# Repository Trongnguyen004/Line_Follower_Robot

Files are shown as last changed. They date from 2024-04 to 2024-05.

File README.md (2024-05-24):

# Line_Follower_Robot
## #Hình ảnh

<p align="center">
  <table>
      <td>
        
      </td>
      <td>
        
      </td>
    
  </table>
</p>

### *Cảm biến QTR8A được tham khảo tại: https://www.pololu.com/product/960

<p align="center">
  <table>
    <tr>
      <td>
        
      </td>
      <td>
        
      </td>  
    </tr>
  </table>
</p>

## #Video

### *Chạy Thử

https://github.com/Trongnguyen004/Line_Follower_Robot/assets/137270832/600d7f80-0cda-47ed-8069-f7d0e4e03a02

https://github.com/Trongnguyen004/Line_Follower_Robot/assets/137270832/67cb3d83-4516-45d8-a72a-21b8230ec6d9

### *Test cảm biến
https://github.com/Trongnguyen004/Line_Follower_Robot/assets/137270832/a73f50d7-3c18-4a8b-9868-28da99d4ba61

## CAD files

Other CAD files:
LineFollowerRobot/Khung xe/Khung.dxf
LineFollowerRobot/Khung xe/Khung.dwg

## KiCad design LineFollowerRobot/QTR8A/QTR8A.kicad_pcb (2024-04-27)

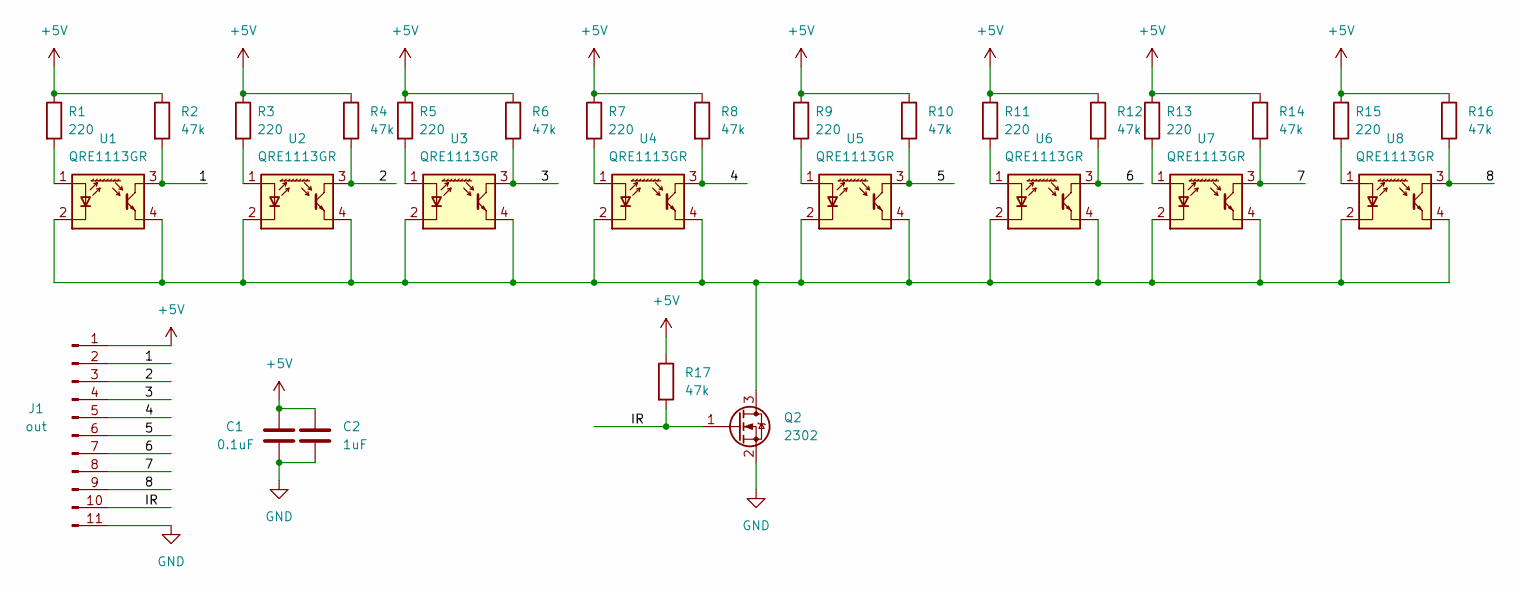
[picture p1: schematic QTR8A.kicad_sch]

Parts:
C1: 0.1uF; C_0805_2012Metric
C2: 1uF; C_0805_2012Metric
J1: out; PinHeader_1x11_P2.54mm_Vertical
Q2: 2302; SOT-23
R1, R3, R5, R7, R9, R11, R13, R15: 220; R_0603_1608Metric
R2, R4, R6, R8, R10, R12, R14, R16, R17: 47k; R_0603_1608Metric
U1, U2, U3, U4, U5, U6, U7, U8: QRE1113GR; OnSemi_CASE100CY

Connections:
+5V: C1.1, C2.1, J1.1, R1.1, R2.1, R3.1, R4.1, R5.1, R6.1, R7.1, R8.1, R9.1, R10.1, R11.1, R12.1, R13.1, R14.1, R15.1, R16.1, R17.1
/1: J1.2, R2.2, U1.3
/2: J1.3, R4.2, U2.3
/3: J1.4, R6.2, U3.3
/4: J1.5, R8.2, U4.3
/5: J1.6, R10.2, U5.3
/6: J1.7, R12.2, U6.3
/7: J1.8, R14.2, U7.3
/8: J1.9, R16.2, U8.3
/IR: J1.10, Q2.1 (G), R17.2
GND: C1.2, C2.2, J1.11, Q2.2 (S)
unnamed: Q2.3 (D), U1.2 (K), U1.4, U2.2 (K), U2.4, U3.2 (K), U3.4, U4.2 (K), U4.4, U5.2 (K), U5.4, U6.2 (K), U6.4, U7.2 (K), U7.4, U8.2 (K), U8.4
unnamed: R1.2, U1.1 (A)
unnamed: R3.2, U2.1 (A)
unnamed: R5.2, U3.1 (A)
unnamed: R7.2, U4.1 (A)
unnamed: R9.2, U5.1 (A)
unnamed: R11.2, U6.1 (A)
unnamed: R13.2, U7.1 (A)
unnamed: R15.2, U8.1 (A)

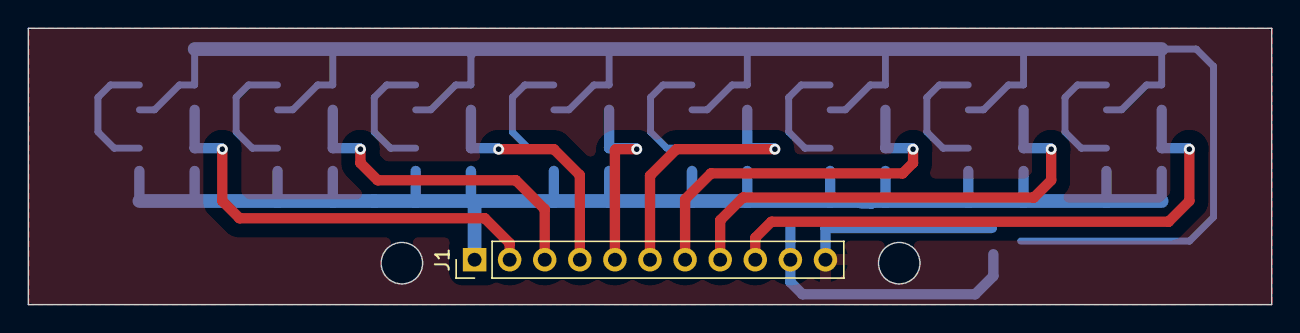
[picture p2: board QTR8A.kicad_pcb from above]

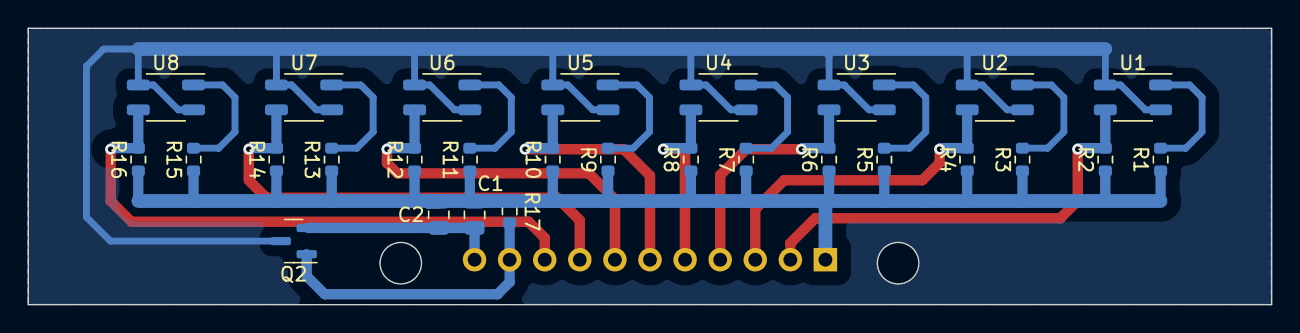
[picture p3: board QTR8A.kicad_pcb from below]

Board: 2 copper layers, 90.0 x 20.0 mm, 29 parts (28 on the bottom side), 20 nets.

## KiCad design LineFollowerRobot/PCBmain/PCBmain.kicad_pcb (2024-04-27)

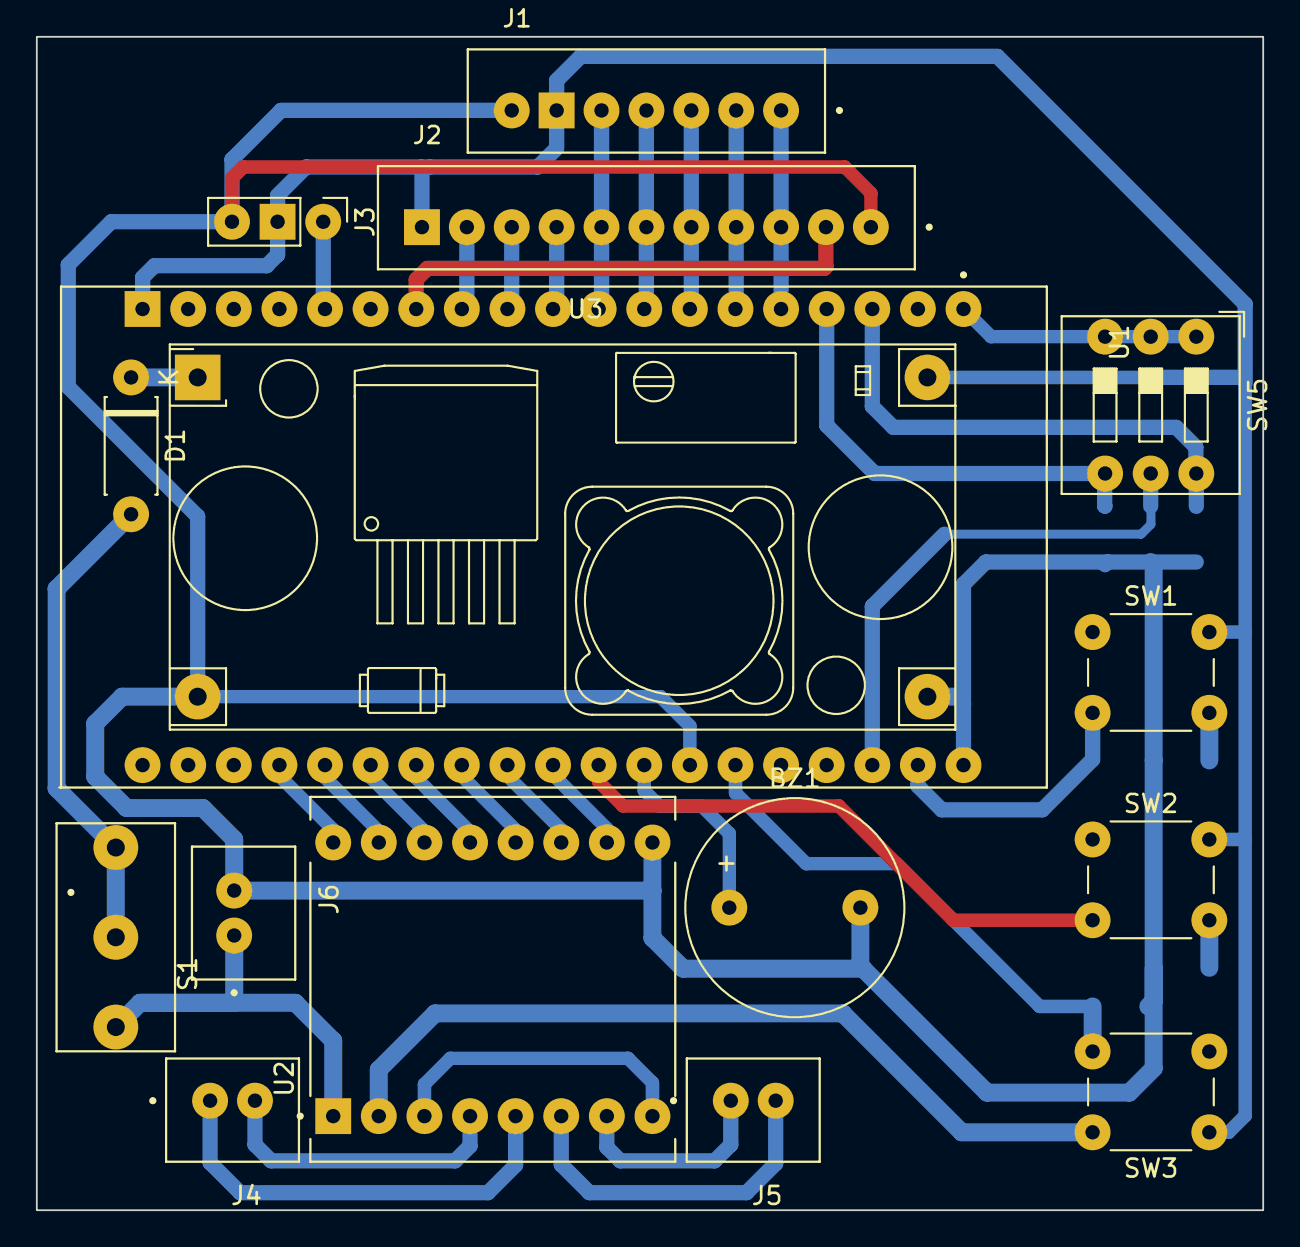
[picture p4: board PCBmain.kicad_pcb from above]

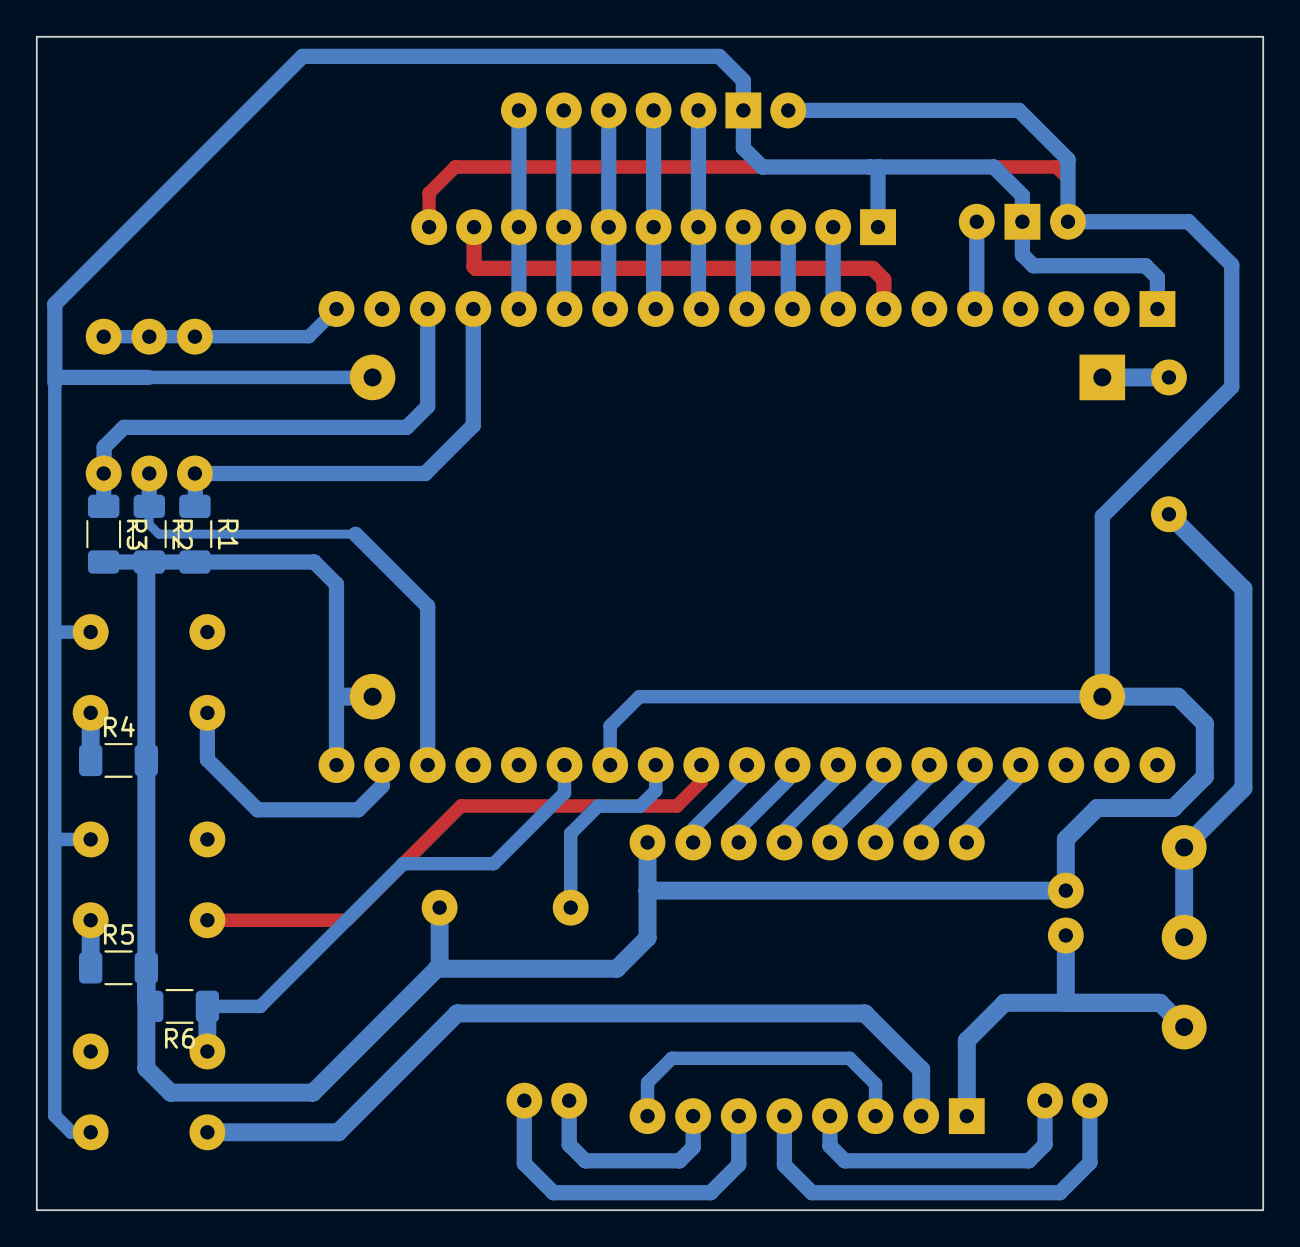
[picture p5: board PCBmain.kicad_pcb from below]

Board: 2 copper layers, 68.3 x 65.3 mm, 22 parts (6 on the bottom side), 33 nets.

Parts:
BZ1: Buzzer; Buzzer_12x9.5RM7.6
D1: 1N4007; D_DO-41_SOD81_P7.62mm_Horizontal
J1: JST_B7B-XH-A_LF__SN_
J2: B11B-XH-A_LF__SN_; JST_B11B-XH-A_LF__SN_
J3: Conn_01x03_Pin; PinHeader_1x03_P2.54mm_Vertical
J4, J5: B2B-XH-A_LF__SN_; JST_B2B-XH-A_LF__SN_
J6: connector; JST_B2B-XH-A_LF__SN_
R1, R2, R3, R4, R5, R6: R; R_1206_3216Metric_Pad1.30x1.75mm_HandSolder
S1: công tắc; SW_EG1218
SW1, SW2, SW3: SW_Push; SW_PUSH_6mm_H4.3mm
SW5: SW_DIP_x03; SW_DIP_SPSTx03_Slide_9.78x9.8mm_W7.62mm_P2.54mm
U1: ESP32-DEVKITC-32D; MODULE_ESP32-DEVKITC-32D
U2: TB6612; MODULE_ROB-14450
U3: Module_LM2596; YAAJ_DCDC_StepDown_LM2596

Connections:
+3.3V: SW5.1, SW5.2, SW5.3, U1.J2-1 (3V3)
+5V: J1.6, J2.11, J3.2, SW1.1, SW2.1, SW3.1, U1.J2-19 (EXT_5V), U2.2 (VCC), U3.4 (Vout)
/1: J1.1, J2.3, U1.J2-5 (IO34)
/2: J1.2, J2.4, U1.J2-6 (IO35)
/3: J1.3, J2.5, U1.J2-7 (IO32)
/4: J1.4, J2.6, U1.J2-8 (IO33)
/5: J1.5, J2.7, U1.J2-9 (IO25)
/6: J2.8, U1.J2-10 (IO26)
/7: J2.9, U1.J2-11 (IO27)
/8: J2.10, U1.J2-12 (IO14)
/A: U1.J3-16 (IO15), U2.16 (PWMA)
/A1: U1.J3-14 (IO0), U2.14 (AI1)
/A2: U1.J3-15 (IO2), U2.15 (AI2)
/B: U1.J3-10 (IO5), U2.10 (PWMB)
/B1: U1.J3-12 (IO16), U2.12 (BI1)
/B2: U1.J3-11 (IO17), U2.11 (BI2)
/But1: R4.1, SW1.2, U1.J3-2 (IO23)
/But2: R5.1, SW2.2, U1.J3-9 (IO18)
/But3: R6.1, SW3.2, U1.J3-6 (IO21)
/Buzz: BZ1.1 (-), U1.J3-8 (IO19)
/IR: J2.2, U1.J2-13 (IO12)
/STBY: U1.J3-13 (IO4), U2.13 (STBY)
/SW1: R1.1, SW5.4, U1.J2-4 (SENSOR_VN)
/SW2: R2.1, SW5.5, U1.J3-3 (IO22)
/SW3: R3.1, SW5.6, U1.J2-3 (SENSOR_VP)
GND: BZ1.2 (+), J1.7, J2.1, J3.3, J6.2, R1.2, R2.2, R3.2, R4.2, R5.2, R6.2, U1.J2-14 (GND1), U1.J3-1 (GND3), U1.J3-7 (GND2), U2.3 (GND), U2.8 (GND), U2.9 (GND), U3.2 (GND), U3.3 (GND)
unnamed: D1.2 (A), S1.1, S1.2
unnamed: D1.1 (K), U3.1 (Vin)
unnamed: J4.2, U2.4 (A01)
unnamed: J4.1, U2.5 (A02)
unnamed: J5.1, U2.7 (B01)
unnamed: J5.2, U2.6 (B02)
VCC: J6.1, S1.3, U2.1 (VM)
